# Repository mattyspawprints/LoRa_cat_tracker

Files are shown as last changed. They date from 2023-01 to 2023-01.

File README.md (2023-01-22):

# LoRa_cat_tracker :smiley_cat:
This cat tracker sends GPS coordinates using LoRa

A Raspberry Pi receives the data and sets a marker at your cat's position onto a map

There is also a portable receiver in case the Raspberry Pi doesn’t receive the data, or you have to search for your cat/collar

leaflet leaflet

©Gregor Wiebe | [Huckleberryking](https://www.huckleberryking.com/)

leaflet

[map](http://hs-augsburg.de/~lekr6621/Mattys_Website/final.html)

## Parts List
Before you buy one of the LoRa boards, check if the board has the correct frequency
- Europe EU868 MHz 
- South America AU915/AS923-1 MHz 
- North America US915 MHz 
- India IN865 MHz 
- Asia AS923 MHz

| Sender | portable receiver | receiver | other parts |
| --- |---| -----| -----|
| [1x CubeCell GPS-6502](https://www.amazon.de/Seamuing-LoRaWAN-Development-ASR6502-intelligente/dp/B08B1G5THB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,aps,110&sr=8-1-spons&sp_csd=d2lkZ2V0TmFtZT1zcF9hdGY&psc=1) | [1x Heltec WiFi LoRa 32 V2](https://www.amazon.de/Display-Entwicklungsboard-Bluetooth-868MHz-915MHz-Flash-IOT/dp/B0B6G8ZVNT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,aps,91&sr=8-7-spons&sp_csd=d2lkZ2V0TmFtZT1zcF9tdGY&th=1) | [1x Raspberry Pi 3](https://www.amazon.de/Raspberry-Pi-Model-ARM-Cortex-A53-Bluetooth/dp/B01CD5VC92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,aps,121&sr=8-2) |[2x 1k resistor](https://www.amazon.de/Widerstand-St%C3%BCck-Kohleschicht-Widerst%C3%A4nde-Resistor/dp/B00IYT9MLC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,aps,87&sr=8-8)|
| [1x Lithium Polymer Battery 3,7V 480mAh](https://www.amazon.de/EEMB-Lithium-Polymer-Ionen-Akku-wiederaufladbarer-Lithium-Ionen-Polymer-Akku-JST-Anschluss/dp/B09DPPXRFY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,7%20480mah&qid=1673031959&sprefix=lipo%203%207%20480mah,aps,85&sr=8-1-spons&sp_csd=d2lkZ2V0TmFtZT1zcF9hdGY&psc=1) | [1x Lithium Polymer Battery 3,7V 1100mAh](https://www.amazon.de/1100mAh-Schutzplatine-Isolierband-1-25-Stecker-ESP32-Entwicklungsplatine/dp/B087LTZW61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,aps,108&sr=8-6) | [1x LoRa breakout board](https://www.amazon.de/gp/product/B084NWDFH1/ref=ppx_yo_dt_b_asin_title_o01_s01?ie=UTF8&psc=1) |[1x 2k resistor](https://www.amazon.de/Widerstand-St%C3%BCck-Kohleschicht-Widerst%C3%A4nde-Resistor/dp/B00IYTI6LE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,aps,85&sr=8-6)|
| [1x active buzzer](https://www.amazon.de/QWORK-Elektronischer-Summer-Active-Kabell%C3%A4nge/dp/B09RFH1T8J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) | [(1x tactile button)](https://www.amazon.de/Youmile-100er-Pack-Miniatur-Mikro-Taster-Tastschalter-Qualit%C3%A4tsschalter-Miniature-6-x-5-mm/dp/B07Q1BXV7T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,aps,124&sr=1-1-26e67082-4f95-42ef-935f-dfc82714a173&th=1) |  |[2x slide switch](https://www.amazon.de/dp/B07VFW4SWS?psc=1&ref=ppx_yo2ov_dt_b_product_details)|
| [1x BLE hm-10 module](https://www.amazon.de/DSD-TECH-Bluetooth-iBeacon-Arduino/dp/B06WGZB2N4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,aps,94&sr=8-1-spons&sp_csd=d2lkZ2V0TmFtZT1zcF9hdGY&psc=1) | [4x Neopixels (1x strip)](https://www.amazon.de/BTF-LIGHTING-adressierbar-Vollfarbiger-wasserdichte-DIY-Projekte/dp/B088FK4SMQ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,aps,85&sr=8-15&th=1) |  |[1x ttl converter](https://www.amazon.de/dp/B089QJZ51Z?ref=ppx_yo2ov_dt_b_product_details&th=1)|
| | |  |[some jumper wires](https://www.amazon.de/AZDelivery-Jumper-Arduino-Raspberry-Breadboard/dp/B074P726ZR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)|
|  | | | [1x breadboard](https://www.amazon.de/AZDelivery-Breadboard-Steckbrett-Kontakten-Arduino/dp/B07K8PQ4B5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,aps,97&sr=8-3&th=1)|

## Case
#### 3D printed
You can print a case for the portable receiver and the sender

  
                                               
                                              ©Gregor Wiebe | [Huckleberryking](https://www.huckleberryking.com/)

  but the case for the sender is a little bit too big for a cat, in my opinion

#### alternative
If you cannot print a 3D case, you also can use heat shrink tubes for the sender and a plastic box for the receiver.
To fit everything in the tube you should use one with at least an inner diameter of 30mm.
For the receiver, you can use, for example, the box that the Heltec board came with. Make holes for the antenna, power switch, display and USB port. In this case, you can use the programable button on the board because the plastic is very thin, and you can push the button through the plastic, so choose the Portable_Receiver_onboardButton sketch and upload it to the white heltec board.

 

 

 

©Gregor Wiebe | [Huckleberryking](https://www.huckleberryking.com/)

 ##  Soldering
 
**Sender**



To make the sender thinner, you can try to remove the plastic socket
Or try to desolder the oled display

  

BLE module: solder wires to gnd and vcc (before you desolder the pin header, you have to configure your BL module, which will be explained later
Also, the red wire of the buzzer to pin 4 and the black one to gnd



Take the connector cable of the CubeCell board and connect the red wire with 
The red wire of the BLE module. Solder these cables to the middle pin of the 
Switch. Take the red battery wire and solder it to the correct pin of the switch.
Solder the three black ground wires together.

**Portable Receiver**



Take the neopixels and solder three wires to it
The data wire to pin 23 of the Heltec board
Vcc to the 3.3 pin
gnd to gnd

Use the connector cable and solder the red wire to the middle pin of the switch
And the lipo red wire to the correct pin

Do this only if you are using the printed case:
Solder a black wire to another gnd pin of the Heltec board, then solder a 1 k resistor 
to The end of the wire. Take the resistor and solder it to one pin of the tactile
Button. On the correct pin solder a wire to it, and this wire to pin 17 of the 
Board. Now solder a wire to the other pin of the pin and the 3.3V pin

Now you can put everything in the receiver case

**Raspberry Pi Receiver**



Solder 11 wires to the LoRa breakout board 
And the antenna to the antenna pin
|Raspberry Pi  | Lora – SX1276 Module |
|--|--|
| 3.3V | 3.3V |
| gnd | gnd |
| GPIO 10 | MOSI |
| GPIO 9 | MISO |
| GPIO 11 | SCK |
| GPIO 8 | Nss / Enable |
| GPIO 4 | DIO 0 |
| GPIO 17 | DIO 1 |
| GPIO 18 | DIO 2 |
| GPIO 27 | DIO 3 |
| GPIO 22 | RST |

 ##  Software
 
### Arduino IDE

Go to https://www.arduino.cc/en/software and download the Arduino IDE

Next, we have to include the libraries for the Heltec boards. 
Open the Arduino IDE and go to file -> preferences
Click on the two squares and paste the three links into it

https://dl.espressif.com/dl/package_esp32_index.json                                                                                  
https://github.com/HelTecAutomation/CubeCell-Arduino/releases/download/V1.5.0/package_CubeCell_index.json                                                    
https://github.com/Heltec-Aaron-Lee/WiFi_Kit_series/releases/download/0.0.6/package_heltec_esp32_index.json

  

### **Sender**

Connect the CubeCell board to your computer and choose the port and the correct board from the manager.

choosing board github ports
  
To test the CubeCell board upload the oledDisplayGPSInfo.ino file
file->examples->OnBoardGPS ->  oledDisplayGPSInfo -> ctrl + u.
If there’s an compile error try to replace line 8 with this 

`SSD1306Wire  display(0x3c, 500000, SDA, SCL ,GEOMETRY_128_64,GPIO10); // addr, freq, sda, scl,resolution, rst`

Put the board outside and wait until the board gets a GPS fix
First time using it could take some time until it gets a fix
Next time it is much faster

If everything is working open the sender sketch which is in the github folder you’ve downloaded

 

 **GPS settings**
 
The default GPS settings are GPS_INIT_TIMEOUT 5 Minutes, 
GPS_SLEEPTIME also 5 Minutes, GPS_UPDATE_TIMEOUT 30 seconds.
If you want that your tracker sleeps longer you can change the sleeptime.
The numbers are in milliseconds. (1 sec = 1000ms)

**LoRa settings**

choose your frequency : 
- Europe EU868 MHz
- South America  AU915/AS923-1 MHz
- North America US915 MHz
- India  IN865 MHz
- Asia AS923 MHz

You also can change the bandwidth, codingrate and spreading factor. Keep in mind if you change these settings you have to change them 
in the code for the receivers too.
Upload the code (ctrl + u)

### **Portable Receiver**

 Now connect the Heltec WiFi board to your computer. Open the portable receiver sketch (downloaded github folder) and choose the Heltec Wifi LoRa V2 and the port.
 
portable receiver frequency

In line 284 change the LoRa frequency. This time it’s called band.



Here you can change the bandwidth, codingrate and sprading factor.
But it has to be the same settings like in the sender sketch.

 

On the left side click on the library manager and search for adafruit neopixel. Install the Adafruit NeoPixel by Adafruit.

Upload the code



BT -> bluetooth connection with senders ble module, the number is the signalstrength

V -> it receives the senderes battery capacity in millivolts

LoRa: 
- zone -> you can set a zone to now wheres your pet at instead of only coordinates
- numbers -> senders coordinates
- RSSI -> LoRa signalstrength
    
### **Raspberry Pi Receiver**

For this receiver I’m using this repository: https://github.com/rpsreal/pySX127x

Download the Raspberry Pi Imager from here: https://www.raspberrypi.com/software/
and Visual Studio Code https://code.visualstudio.com/
Open the imager and insert a micro sd cart into your computer.

rp-imager

Choose the Raspberry Pi Os (32-Bit) operating system and your sd card.
Click on the gear and configurate following settings.

rp-imager settings

- enable Hostname: raspberrypi
- enable ssh
- enter pi as username and choose a password
- set your Wifi SSID and password
- set your country

Save everything and click on the write button
After the os is written to your sd card you can remove it and insert it into your Raspberry Pi. Plug the power cable into your Pi.
Open Visual Studio Code and click on the left side on the extensions icon. Search for remote ssh and install it.





Wait couple minutes to let your Pi boot up.
Click on the green icon in the bottom left corner and choose connect current window to host -> add new ssh host -> write ssh pi@raspberrypi and press enter -> C:\user\.ssh\config -> click again on the green icon in the bottom left corner and choose connect current window to host -> Linux -> raspberrypi -> continue -> enter your password 
Now you are connected to your Pi. Click on file -> open folder -> \home\pi
Terminal -> new terminal
enter every line and press enter if it ask to continue enter y

    sudo apt-get update
    sudo apt-get upgrade
    sudo apt-get install apache2
    sudo mkdir /var/www/html/tracker
  
    sudo raspi-config nonint do_spi 0
    sudo apt-get install python-dev python3-dev
    sudo apt-get install python-pip python3-pip
    
    pip install RPi.GPIO
    pip install spidev
    pip install pyLoRa

    sudo apt-get install git
    git clone https://github.com/rpsreal/pySX127x

After everything is installed enter sudo reboot. Wait a minute and connect with your pi again (green icon in the buttom left corner).

Drag the website.py file from the downloaded github folder and drop it into the pi folder in visual studio code.



Now right click under the website file -> new file -> array.txt
Go to the terminal again. To run the code enter `python3 website.py`

To stop the code press ctrl + c.



To change the LoRa settings click on the website.py file.
Remember to change your frequency and set the same bandwidth and spreading factor like the sender.

### **Map**

for the map I'm using Leaflet. You can change the pictures and the offset of the paw prints


IF you changed the code press ctrl + s and run the code. 

After your Raspberry Pi received some coordinates you can check them out here: http://raspberrypi/tracker/index.html

### **DSD TECH Bluetooth Tools**

Because i use a module from DSD TECH i configurated my module with their software 
http://www.dsdtech-global.com/2017/11/dsd-tech-bluetooth-config-tool.html
Use a ttl converter and connect 
|TTL converter| BLE module |
|--|--|
| 5V | vcc |
| gnd | gnd |
| RX | TX |
| TX | RX |

 



In the software choose your com port, click on open and go to the hm-10 tab
Click on ‘test’ to check if there is a connection

If in the consol comes a ok back everything is good

First change the modules name (e.g. your cats name) -> set

Auth Mode: Auth not need PIN -> set

PIN: choose a pin  -> set




Go to the AT Comand tab

ASCII: 

AT+PWRM0 -> send		(auto sleep)

AT+MODE2 -> send		(Remote Control Mode + Transmission Mode)

AT+BEFC000 -> send		(Set Module pin output state, After power supplied)

AT+AFTC000 -> send		(Set Module pin output state, After connection is established) 
In my case i wasn’t able to change the service and characteristics uuid with ascii (AT+UUID0xFFE4 | AT+CHAR0xFFE5) so i converted these two camands in hexadecimal

HEX:

41 54 2B 55 55 49 44 30 78 46 46 45 34    ->    send	(Service uuid)

41 54 2B 43 48 41 52 30 78 46 46 45 35    ->    send	(characteristics uuid)

Now your module is configurated. Click on close icon and unplug the ttl converter. Plug it again into your computer and search with your smartphone for bluetooth devices. If you are able to find your module with the name you set everything is fine.
If you have an iPhone it coul be possible that you are unable to see the module in your bluetooth devices.
Take the portable receiver and press the button now it will search for the ble module. When they are connected the neopixels begin to glow and show the distance between these two devices.

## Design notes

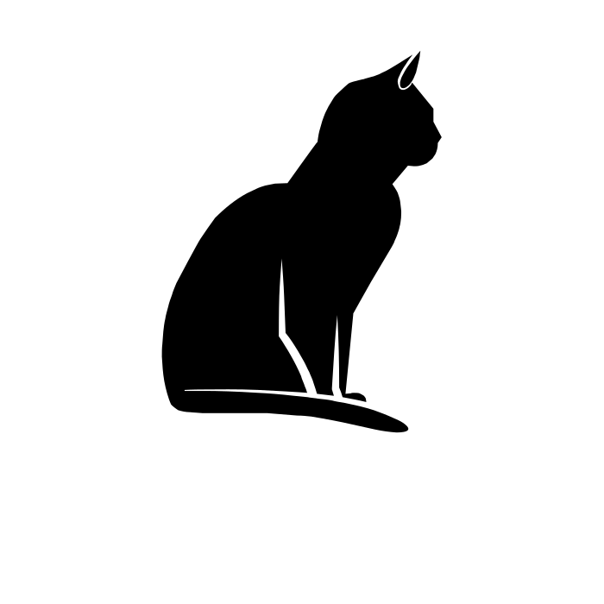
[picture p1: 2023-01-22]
Leaflet/images/noun-black-cat.png

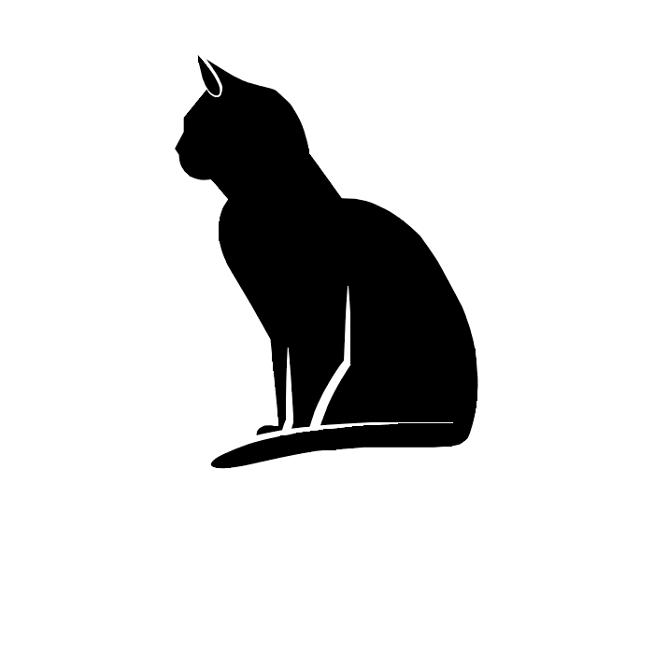
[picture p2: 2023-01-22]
Leaflet/images/black_cat_left.png

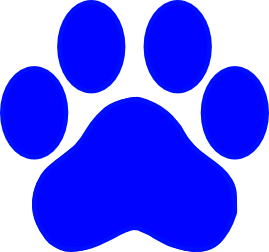
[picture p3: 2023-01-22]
Leaflet/images/pawBlue.png

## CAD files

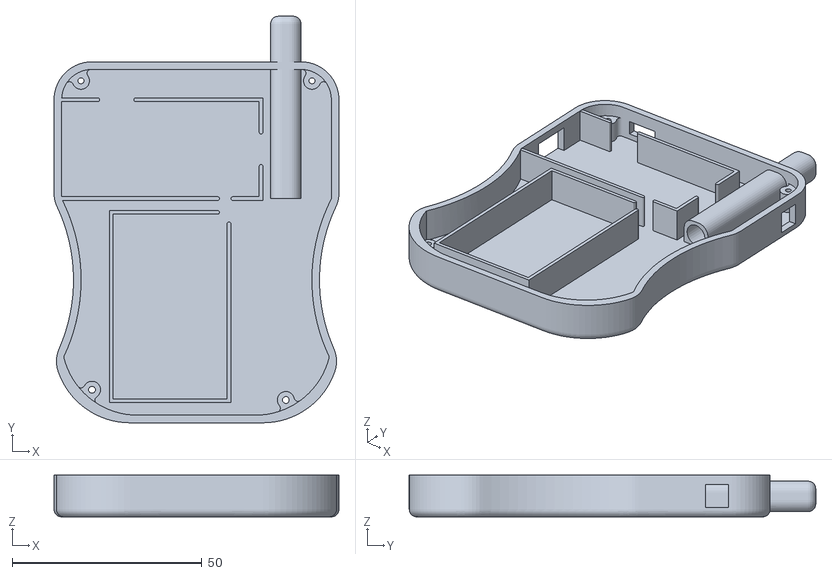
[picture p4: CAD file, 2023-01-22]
3D Cases/Portable_Receiver/Portable_Receiver_bottom.stl
75.0 x 107.0 x 11.0

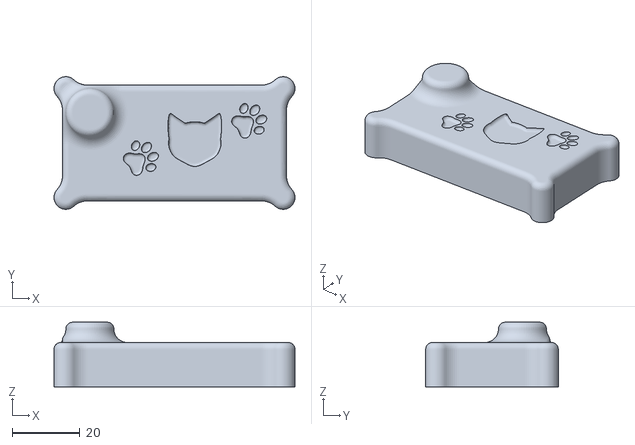
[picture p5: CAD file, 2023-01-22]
3D Cases/Sender/Sender_top.stl
71.2 x 39.2 x 19.1

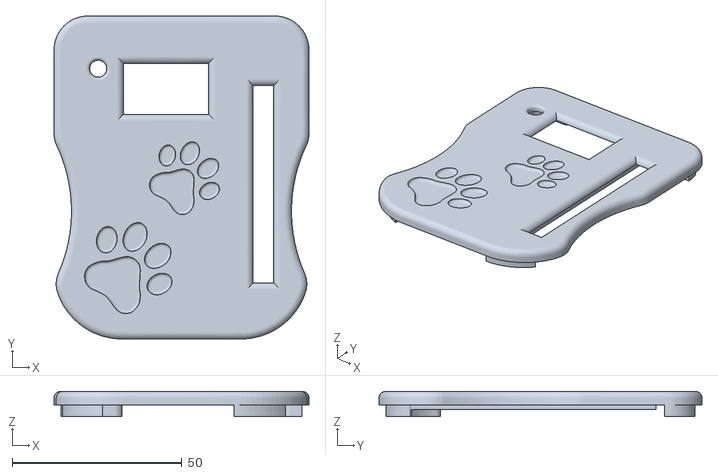
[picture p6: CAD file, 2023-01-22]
3D Cases/Portable_Receiver/Portable_Receiver_top.stl
75.0 x 95.0 x 7.50

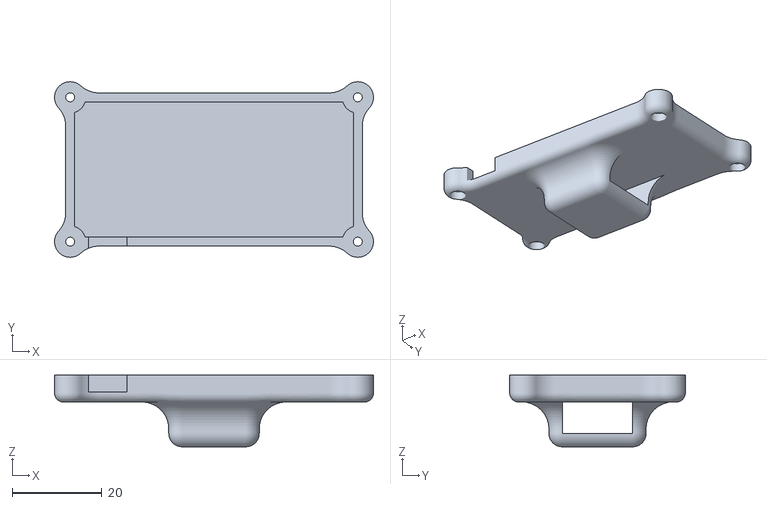
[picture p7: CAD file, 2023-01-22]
3D Cases/Sender/Sender_bottom.stl
71.2 x 39.2 x 16.0

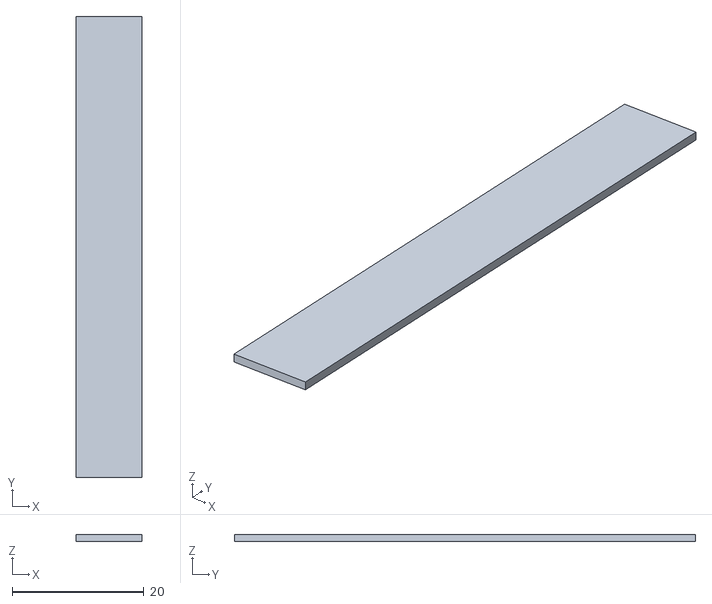
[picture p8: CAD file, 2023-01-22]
3D Cases/Portable_Receiver/Portable_Receiver_transperent.stl
10.0 x 70.0 x 1.00

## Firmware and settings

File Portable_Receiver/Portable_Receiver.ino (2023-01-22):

#include <Adafruit_NeoPixel.h>
#ifdef __AVR__
 #include <avr/power.h> // Required for 16 MHz Adafruit Trinket
#endif

// Which pin on the Arduino is connected to the NeoPixels?
#define PIN        23 // On Trinket or Gemma, suggest changing this to 1

// How many NeoPixels are attached to the Arduino?
#define NUMPIXELS 4 // Popular NeoPixel ring size

#define buttonPin 17

int buttonValue = 0;

int bright;

Adafruit_NeoPixel pixels(NUMPIXELS, PIN, NEO_GRB + NEO_KHZ800);

#define DELAYVAL 500 // Time (in milliseconds) to pause between pixels



#include "heltec.h"


#include "BLEDevice.h"

//BLE

/* Specify the Service UUID of Server */
static BLEUUID serviceUUID("0000ffe4-0000-1000-8000-00805f9b34fb");
/* Specify the Characteristic UUID of Server */
static BLEUUID    charUUID("0000ffe5-0000-1000-8000-00805f9b34fb");

static boolean doConnect = false;
static boolean connected = false;
static boolean doScan = false;
static BLERemoteCharacteristic* pRemoteCharacteristic;
static BLEAdvertisedDevice* myDevice;

bool deviceConnected = false;
bool oldDeviceConnected = false;

BLEClient*  pClient  = BLEDevice::createClient();

String rssiBLE = "";
int rssiLED;
String bluet = "N/A";

static void notifyCallback(BLERemoteCharacteristic* pBLERemoteCharacteristic,
                            uint8_t* pData, size_t length, bool isNotify)
{
  Serial.print("Notify callback for characteristic ");
  Serial.print(pBLERemoteCharacteristic->getUUID().toString().c_str());
  Serial.print(" of data length ");
  Serial.println(length);
  Serial.print("data: ");
  Serial.println((char*)pData);
}

class MyClientCallback : public BLEClientCallbacks
{
  void onConnect(BLEClient* pclient)
  {
    deviceConnected = true;
  }

  void onDisconnect(BLEClient* pclient)
  {
    deviceConnected = false;
    connected = false;
  }
};

/* Start connection to the BLE Server */
bool connectToServer()
{
 
  pClient->setClientCallbacks(new MyClientCallback());

    /* Connect to the remote BLE Server */
  pClient->connect(myDevice);  // if you pass BLEAdvertisedDevice instead of address, it will be recognized type of peer device address (public or private)
  Heltec.display->drawString(45, 0, "bonding");
     Heltec.display->display();


    /* Obtain a reference to the service we are after in the remote BLE server */
  BLERemoteService* pRemoteService = pClient->getService(serviceUUID);
  if (pRemoteService == nullptr)
  {
    pClient->disconnect();
    return false;
  }



  /* Obtain a reference to the characteristic in the service of the remote BLE server */
  pRemoteCharacteristic = pRemoteService->getCharacteristic(charUUID);
  if (pRemoteCharacteristic == nullptr)
  {
    pClient->disconnect();
    return false;
  }
  Serial.println(" - Found our characteristic");

  /* Read the value of the characteristic */
  /* Initial value is 'Hello, World!' */
  if(pRemoteCharacteristic->canRead())
  {
    std::string value = pRemoteCharacteristic->readValue();
  }

  if(pRemoteCharacteristic->canNotify())
  {
    pRemoteCharacteristic->registerForNotify(notifyCallback);

  }

    connected = true;
    return true;
}
/* Scan for BLE servers and find the first one that advertises the service we are looking for. */
class MyAdvertisedDeviceCallbacks: public BLEAdvertisedDeviceCallbacks
{
 /* Called for each advertising BLE server. */
  void onResult(BLEAdvertisedDevice advertisedDevice)
  {

    /* We have found a device, let us now see if it contains the service we are looking for. */
    if (advertisedDevice.haveServiceUUID() && advertisedDevice.isAdvertisingService(serviceUUID))
    {
      BLEDevice::getScan()->stop();
      myDevice = new BLEAdvertisedDevice(advertisedDevice);
      doConnect = true;
      doScan = true;

    }
  }
};


void onButton(){
  Serial.println("button pressed");
  if(connected){
    // String newValue = "beep"; //String für Buzzer am CubeCell Board
    String newValue = "AT+PIO41"; //String für Buzzer direkt am BLE Modul
    Serial.println(newValue);

    
    /* Set the characteristic's value to be the array of bytes that is actually a string */
    pRemoteCharacteristic->writeValue(newValue.c_str(), newValue.length());
    /* You can see this value updated in the Server's Characteristic */
        delay(500); // bluetooth stack will go into congestion, if too many packets are sent, in 6 hours test i was able to go as low as 3ms
        newValue = "AT+PIO40";
        pRemoteCharacteristic->writeValue(newValue.c_str(), newValue.length());    
  }else {
          Heltec.display->drawString(45, 0, "search");
          Heltec.display->display();
          BLEDevice::init("ESP32-BLE-Client");

          esp_ble_tx_power_set(ESP_BLE_PWR_TYPE_DEFAULT, ESP_PWR_LVL_P9); 
          esp_ble_tx_power_set(ESP_BLE_PWR_TYPE_ADV, ESP_PWR_LVL_P9);
          esp_ble_tx_power_set(ESP_BLE_PWR_TYPE_SCAN ,ESP_PWR_LVL_P9);  



            /* Retrieve a Scanner and set the callback we want to use to be informed when we
              have detected a new device.  Specify that we want active scanning and start the
              scan to run for 5 seconds. */
            BLEScan* pBLEScan = BLEDevice::getScan();
            pBLEScan->setAdvertisedDeviceCallbacks(new MyAdvertisedDeviceCallbacks());
            pBLEScan->setInterval(1349);
            pBLEScan->setWindow(449);
            pBLEScan->setActiveScan(true);
            pBLEScan->start(10, false);
            }
   

}

//battery
#include <Arduino.h>
#include <esp_adc_cal.h>
#include <driver/adc.h>
#define MAXBATT                 4200    // The default Lipo is 4200mv when the battery is fully charged.
#define LIGHT_SLEEP_VOLTAGE     3750    // Point where start light sleep
#define MINBATT                 3200    // The default Lipo is 3200mv when the battery is empty...this WILL be low on the 3.3v rail specs!!!

#define VOLTAGE_DIVIDER         3.20    // Lora has 220k/100k voltage divider so need to reverse that reduction via (220k+100k)/100k on vbat GPIO37 or ADC1_1 (early revs were GPIO13 or ADC2_4 but do NOT use with WiFi.begin())
#define DEFAULT_VREF            1100    // Default VREF use if no e-fuse calibration
#define VBATT_SAMPLE            500     // Battery sample rate in ms
#define VBATT_SMOOTH            50      // Number of averages in sample
#define ADC_READ_STABILIZE      5       // in ms (delay from GPIO control and ADC connections times)
#define LO_BATT_SLEEP_TIME      10*60*1000*1000     // How long when low batt to stay in sleep (us)
#define HELTEC_V2_1             1       // Set this to switch between GPIO13(V2.0) and GPIO37(V2.1) for VBatt ADC.
#define VBATT_GPIO              21      // Heltec GPIO to toggle VBatt read connection ... WARNING!!! This also connects VEXT to VCC=3.3v so be careful what is on header.  Also, take care NOT to have ADC read connection in OPEN DRAIN when GPIO goes HIGH
#define __DEBUG                 0       // DEBUG Serial output

uint16_t Sample();
void drawBattery(uint16_t, bool = false);

esp_adc_cal_characteristics_t *adc_chars;

// Poll the proper ADC for VBatt on Heltec Lora 32 with GPIO21 toggled
uint16_t ReadVBatt() {
  uint16_t reading = 666;

  digitalWrite(VBATT_GPIO, LOW);              // ESP32 Lora v2.1 reads on GPIO37 when GPIO21 is low
  delay(ADC_READ_STABILIZE);                  // let GPIO stabilize
  #if (defined(HELTEC_V2_1))
  pinMode(ADC1_CHANNEL_1, OPEN_DRAIN);        // ADC GPIO37
  reading = adc1_get_raw(ADC1_CHANNEL_1);
  pinMode(ADC1_CHANNEL_1, INPUT);             // Disconnect ADC before GPIO goes back high so we protect ADC from direct connect to VBATT (i.e. no divider)
  #else
  pinMode(ADC2_CHANNEL_4, OPEN_DRAIN);        // ADC GPIO13
  adc2_get_raw(ADC2_CHANNEL_4,ADC_WIDTH_BIT_12,&reading);
  pinMode(ADC2_CHANNEL_4, INPUT);             // Disconnect ADC before GPIO goes back high so we protect ADC from direct connect to VBATT (i.e. no divider
  #endif

  uint16_t voltage = esp_adc_cal_raw_to_voltage(reading, adc_chars);  
  voltage*=VOLTAGE_DIVIDER;

  return voltage;
}

//  Use a buffer to average/sample ADC
uint16_t Sample() {
  static uint8_t i = 0;
  static uint16_t samp[VBATT_SMOOTH];
  static int32_t t = 0;
  static bool f = true;
  if(f){ for(uint8_t c=0;c<VBATT_SMOOTH;c++){ samp[c]=0; } f=false; }   // Initialize the sample array first time
  t -= samp[i];   // doing a rolling recording, so remove the old rolled around value out of total and get ready to put new one in.
  if (t<0) {t = 0;}

  // ADC read
  uint16_t voltage = ReadVBatt();

  samp[i]=voltage;
  #if defined(__DEBUG) && __DEBUG > 0

  #endif
  t += samp[i];

  if(++i >= VBATT_SMOOTH) {i=0;}
  uint16_t s = round(((float)t / (float)VBATT_SMOOTH));
  #if defined(__DEBUG) && __DEBUG > 0

  #endif

  return s;
}


void drawBattery(uint16_t voltage, bool sleep) {

  uint16_t v = voltage;
  if (v < MINBATT) {v = MINBATT;}
  if (v > MAXBATT) {v = MAXBATT;}
  double pct = map(v,MINBATT,MAXBATT,0,100);
  uint8_t bars = round(pct / 10.0);

  uint16_t rnd = round(voltage/10.0);
  Serial.println(rnd);

  if (rnd > 413 || rnd < 380){
    Heltec.display->drawString(1,14,String(round(voltage/10.0)/100.0)+"V");

  }

  #if defined(__DEBUG) && __DEBUG > 0
  static uint8_t c = 0;
  if ((c++ % 10) == 0) {
    c = 1;
 
  }
  #endif
}



//LoRa
#define BAND    868E6  //you can set band here directly,e.g. 868E6,915E6
String rssiLoRa = " ";
String snr = " ";
String packSize = "--";
String packet ;
String str ;
String sublat ;
// int sublatsplit ;
String sublon ;
// int sublonsplit ;
String position;
String battery;

String fence;
int indexLON ;
int indexV ;


void DisplayData(){
  Heltec.display->clear();

  //battery
  uint16_t voltage = Sample();
  drawBattery(voltage, voltage < LIGHT_SLEEP_VOLTAGE);

  //BLE
  Heltec.display->drawString(0, 0, bluet);  
  Heltec.display->drawString(25, 0, rssiBLE); 

  //LoRa
  Heltec.display->drawString(0, 30, "LoRa:");
  Heltec.display->drawString(10, 45, position); 
  Heltec.display->drawStringMaxWidth(35 , 30 , 128, fence);
 
  Heltec.display->drawStringMaxWidth(85 , 0 , 128, battery);   
  Heltec.display->drawString(100, 20, snr); 
  Heltec.display->drawString(100, 30, rssiLoRa);  
  Heltec.display->display();
}

void cbk(int packetSize) {
  packet ="";

  packSize = String(packetSize,DEC);
  for (int i = 0; i < packetSize; i++) { packet += (char) LoRa.read();  }
  rssiLoRa = String(LoRa.packetRssi(), DEC) ;
  snr = (LoRa.packetSnr(), DEC) ;
  

  
  str = packet;
  indexLON = str.indexOf(' ');
  indexV = str.indexOf('V');
  sublat = str.substring(0, indexLON);
  sublon = str.substring(indexLON + 1, indexV - 5);
  battery = str.substring(indexV - 4, indexV + 1);
  position = sublat + " " + sublon;
  
  //setting zones
  if (sublat.toFloat() > 48.741537 && sublat.toFloat() < 48.741653 && sublon.toFloat() > 10.788777 && sublon.toFloat() < 10.789115) {
    fence = "at home";
  }else if(sublat.toFloat() > 48.739608 && sublat.toFloat() < 48.740880 && sublon.toFloat() > 10.790100 && sublon.toFloat() < 10.790737){
    fence = "forest";
  }else {
    fence = "unknown";
  }
  
}


void setup()
{
  Heltec.begin(true /*DisplayEnable Enable*/, true /*Heltec.Heltec.Heltec.LoRa Disable*/, true /*Serial Enable*/, true /*PABOOST Enable*/, BAND /*long BAND*/);
  
  //battery
  // Characterize ADC at particular atten
  #if (defined(HELTEC_V2_1))
  adc_chars = (esp_adc_cal_characteristics_t*)calloc(1, sizeof(esp_adc_cal_characteristics_t));
  esp_adc_cal_value_t val_type = esp_adc_cal_characterize(ADC_UNIT_1, ADC_ATTEN_DB_6, ADC_WIDTH_BIT_12, DEFAULT_VREF, adc_chars);
  adc1_config_width(ADC_WIDTH_BIT_12);
  adc1_config_channel_atten(ADC1_CHANNEL_1,ADC_ATTEN_DB_6);
  #else
  // Use this for older V2.0 with VBatt reading wired to GPIO13
  adc_chars = (esp_adc_cal_characteristics_t*)calloc(1, sizeof(esp_adc_cal_characteristics_t));
  esp_adc_cal_value_t val_type = esp_adc_cal_characterize(ADC_UNIT_2, ADC_ATTEN_DB_6, ADC_WIDTH_BIT_12, DEFAULT_VREF, adc_chars);
  adc2_config_channel_atten(ADC2_CHANNEL_4,ADC_ATTEN_DB_6);
  #endif

  #if defined(__DEBUG) && __DEBUG > 0
  Serial.printf("ADC Calibration: ");
  if (val_type == ESP_ADC_CAL_VAL_EFUSE_VREF) {
      Serial.printf("eFuse Vref\n");
  } else if (val_type == ESP_ADC_CAL_VAL_EFUSE_TP) {
      Serial.printf("Two Point\n");
  } else {
      Serial.printf("Default[%dmV]\n",DEFAULT_VREF);
  }
  #else
  if (val_type);    // Suppress warning
  #endif

 #if defined(__DEBUG) && __DEBUG >= 1
 
  #else
  if (val_type);    // Suppress warning
  #endif

  // Prime the Sample register
  for (uint8_t i = 0;i < VBATT_SMOOTH;i++) {
    Sample();
  }

  pinMode(VBATT_GPIO,OUTPUT);
  digitalWrite(VBATT_GPIO, LOW);              // ESP32 Lora v2.1 reads on GPIO37 when GPIO21 is low
  delay(ADC_READ_STABILIZE);                  // let GPIO stabilize




  //LoRa

  //LoRa.setSpreadingFactor(7);
  LoRa.setSpreadingFactor(9);
  // LoRa.setSignalBandwidth(250E3);
  LoRa.setSignalBandwidth(125E3);
  // LoRa.setSignalBandwidth(41.7E3);
  LoRa.setCodingRate4(1);
  LoRa.setSyncWord(0x12);   //0x34
  LoRa.setPreambleLength(8);
  
  //display
  
  Heltec.display->init(); 
  Heltec.display->setFont(ArialMT_Plain_10);
  Heltec.display->drawString(0, 0, "Empfänger");
  Heltec.display->display();
  delay(500);
  Heltec.display->clear();
  Heltec.display->display();

  #if defined(__AVR_ATtiny85__) && (F_CPU == 16000000)
  clock_prescale_set(clock_div_1);
  #endif
  // END of Trinket-specific code.

  pixels.begin(); // INITIALIZE NeoPixel strip object (REQUIRED)
  pixels.setBrightness(50);
  pixels.clear();
  pixels.show();
  Serial.println("Starting Arduino BLE Client application...");
  pinMode(buttonPin, INPUT);
}


void loop()
{

int packetSize = LoRa.parsePacket();
  if (packetSize) { cbk(packetSize);  }
  delay(10);   

  DisplayData();
 rssiBLE = pClient->getRssi();
 rssiLED = pClient->getRssi();
  buttonValue =  digitalRead(buttonPin);
Serial.println(buttonValue);

   if (!deviceConnected) {
    bluet = "N/A";

    pixels.clear();
      pixels.setPixelColor(0, pixels.Color(0, 0, 0));
      pixels.setPixelColor(1, pixels.Color(0, 0, 0));
      pixels.setPixelColor(2, pixels.Color(0, 0, 0));
      pixels.setPixelColor(3, pixels.Color(125, 0, 255));
      
      pixels.show();
   }else{
    bluet = "BT";

    if (rssiLED < -140){
      pixels.clear();
      pixels.setPixelColor(0, pixels.Color(255, 0, 0));
      pixels.setPixelColor(1, pixels.Color(0, 0, 0));
      pixels.setPixelColor(2, pixels.Color(0, 0, 0));
      pixels.setPixelColor(3, pixels.Color(0, 0, 0));
      
      pixels.show();
    }else if (rssiLED < -110){
      pixels.clear();
      pixels.setPixelColor(0, pixels.Color(255, 0, 0));
      pixels.setPixelColor(1, pixels.Color(255, 0, 0));
      pixels.setPixelColor(2, pixels.Color(0, 0, 0));
      pixels.setPixelColor(3, pixels.Color(0, 0, 0));
     
      pixels.show();
    }else if (rssiLED < -105){
      pixels.clear();
      pixels.setPixelColor(0, pixels.Color(255, 0, 0));
      pixels.setPixelColor(1, pixels.Color(255, 0, 0));
      pixels.setPixelColor(2, pixels.Color(255, 0, 0));
      pixels.setPixelColor(3, pixels.Color(0, 0, 0));
      
      pixels.show();
    }else if (rssiLED < -100){
      pixels.clear();
      pixels.setPixelColor(0, pixels.Color(255, 0, 0));
      pixels.setPixelColor(1, pixels.Color(255, 0, 0));
      pixels.setPixelColor(2, pixels.Color(255, 0, 0));
      pixels.setPixelColor(3, pixels.Color(255, 0, 0));
 
      pixels.show();
    }else if (rssiLED < -90){
      pixels.clear();
      pixels.setPixelColor(0, pixels.Color(0, 255, 0));
      pixels.setPixelColor(1, pixels.Color(255, 0, 0));
      pixels.setPixelColor(2, pixels.Color(255, 0, 0));
      pixels.setPixelColor(3, pixels.Color(255, 0, 0));
      
      pixels.show();
    }else if (rssiLED < -70){
      pixels.clear();
      pixels.setPixelColor(0, pixels.Color(0, 255, 0));
      pixels.setPixelColor(1, pixels.Color(0, 255, 0));
      pixels.setPixelColor(2, pixels.Color(255, 0, 0));
      pixels.setPixelColor(3, pixels.Color(255, 0, 0));
      
      pixels.show();
    }else if (rssiLED < -60){
      pixels.clear();
      pixels.setPixelColor(0, pixels.Color(0, 255, 0));
      pixels.setPixelColor(1, pixels.Color(0, 255, 0));
      pixels.setPixelColor(2, pixels.Color(0, 255, 0));
      pixels.setPixelColor(3, pixels.Color(255, 0, 0));
      
      pixels.show();   
    }else if (rssiLED < -50){
      pixels.clear();
      pixels.setPixelColor(0, pixels.Color(0, 255, 0));
      pixels.setPixelColor(1, pixels.Color(0, 255, 0));
      pixels.setPixelColor(2, pixels.Color(0, 255, 0));
      pixels.setPixelColor(3, pixels.Color(0, 255, 0));
      
      pixels.show();
    }else {
      pixels.clear();
      pixels.setPixelColor(0, pixels.Color(0, 0, 0));
      pixels.setPixelColor(1, pixels.Color(0, 0, 0));
      pixels.setPixelColor(2, pixels.Color(0, 255, 180));
      pixels.setPixelColor(3, pixels.Color(0, 255, 180));
      
      pixels.show();
    }
   }
  
  if (buttonValue == 1){
    onButton();    
  }

  /* If the flag "doConnect" is true, then we have scanned for and found the desired
     BLE Server with which we wish to connect.  Now we connect to it.  Once we are 
     connected we set the connected flag to be true. */
  if (doConnect == true)
  {
    if (connectToServer())
    {
      Serial.println("We are now connected to the BLE Server.");
    } 
    else
    {
      Serial.println("We have failed to connect to the server; there is nothin more we will do.");
    }
    doConnect = false;
  }

if (!deviceConnected && oldDeviceConnected) { 
        oldDeviceConnected = deviceConnected;

    }
    // connecting
    if (deviceConnected && !oldDeviceConnected) {
        // do stuff here on connecting
        oldDeviceConnected = deviceConnected;
    }  


  /* If we are connected to a peer BLE Server, update the characteristic each time we are reached
     with the current time since boot */
  
  
  
  delay(500); /* Delay a second between loops */
}

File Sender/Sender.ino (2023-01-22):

#include <Arduino.h>
#include "GPS_Air530Z.h"
#include "LoRaWan_APP.h"



//if GPS module is Air530Z, use this
Air530ZClass GPS;

typedef enum {
  STATUS_LPM = 0,
  STATUS_UPDATE_GPS
} dev_status;

int indexnew;
char str_latitude[27];
char str_longitude[27];
int counter = 0;

//fisrt fix timeout
#define GPS_INIT_TIMEOUT 300000  // 300sec/5min

//sleep time until next GPS update
#define GPS_SLEEPTIME 300000  // 300sec/5min


//when gps waked, if in GPS_UPDATE_TIMEOUT, gps not fixed then into low power mode
#define GPS_UPDATE_TIMEOUT 30000  // 30sec/0,5min

//once fixed, GPS_CONTINUE_TIME later into low power mode
#define GPS_CONTINUE_TIME 5000  // 5sec/

static TimerEvent_t autoGPS;
dev_status mcu_status;
uint32_t starttime;

int32_t fracPart(double val, int n) {
  return (int32_t)((val - (int32_t)(val)) * pow(10, n));
}


/*
 * set LoraWan_RGB to 1,the RGB active in loraWan
 * RGB red means sending;
 * RGB green means received done;
 */
#ifndef LoraWan_RGB
#define LoraWan_RGB 0
#endif

#define RF_FREQUENCY 868000000  // Hz

#define TX_OUTPUT_POWER 14  // dBm

#define LORA_BANDWIDTH 0         // [0: 125 kHz, \
                                 //  1: 250 kHz, \
                                 //  2: 500 kHz, \
                                 //  3: Reserved \
                                 
#define LORA_SPREADING_FACTOR 7  // [SF7..SF12]
#define LORA_CODINGRATE 1        // [1: 4/5, \
                                 //  2: 4/6, \
                                 //  3: 4/7, \
                                 //  4: 4/8]
#define LORA_PREAMBLE_LENGTH 8   // Same for Tx and Rx
#define LORA_SYMBOL_TIMEOUT 0    // Symbols
#define LORA_FIX_LENGTH_PAYLOAD_ON false
#define LORA_IQ_INVERSION_ON false


#define RX_TIMEOUT_VALUE 1000
#define BUFFER_SIZE 40  // Define the payload size here

char txpacket[BUFFER_SIZE];
char rxpacket[BUFFER_SIZE];

static RadioEvents_t RadioEvents;

double txNumber;

int16_t rssi, rxSize;
unsigned long lastMillis;

uint16_t voltage;


void onAutoGPS() {
  TimerStop(&autoGPS);
  mcu_status = STATUS_UPDATE_GPS;
}

void gpsUpdate(uint32_t timeout, uint32_t continuetime) {
  //VextOFF();// oled power on;
  delay(10);

  GPS.begin();
  starttime = millis();
  while ((millis() - starttime) < timeout) {
    while (GPS.available() > 0) {
      GPS.encode(GPS.read());
    }

    // gps fixed in a second
    if (GPS.location.age() < 1000) {
      break;
    }
  }

  //if gps fixed update gps and print gps info every 1 second
  if (GPS.location.age() < 1000) {
    starttime = millis();
    uint32_t printinfo = 0;
    while ((millis() - starttime) < continuetime) {
      while (GPS.available() > 0) {
        GPS.encode(GPS.read());
      }

      if ((millis() - starttime) > printinfo) {
        printinfo += 1000;
        int index;
        char str_la[27];
        index = sprintf(str_la, "%d.%d", (int)GPS.location.lat(), fracPart(GPS.location.lat(), 6));
        str_la[index] = 0;
    

        char str_lo[27];
        index = sprintf(str_lo, "%d.%d", (int)GPS.location.lng(), fracPart(GPS.location.lng(), 6));
        str_lo[index] = 0;


        char* cmp_la = strstr(str_la, str_latitude); 
        char* cmp_lo = strstr(str_lo, str_longitude); 

        if(cmp_la && cmp_lo){
          counter ++;

          if (counter >= 6) {          
            sprintf(txpacket + strlen(txpacket), " %s", "R");  //add to the end of package  
            Radio.Send((uint8_t *)txpacket, strlen(txpacket));  //send the package out   
            delay (500);
            CySoftwareReset();   
          }    
        }



        sprintf(txpacket, "%s %s", str_la, str_lo);  //start a package
      }
    }
  } else  //if gps no fixed waited for 2s in to lowpowermode
  {
    
    int index;
    char str_la[27];
    index = sprintf(str_la, "%d.%d", (int)GPS.location.lat(), fracPart(GPS.location.lat(), 6));
    str_la[index] = 0;

    char str_lo[27];
    index = sprintf(str_lo, "%d.%d", (int)GPS.location.lng(), fracPart(GPS.location.lng(), 6));
    str_lo[index] = 0;

    char* cmp_la = strstr(str_la, str_latitude);      
    char* cmp_lo = strstr(str_lo, str_longitude); 

     if(cmp_la && cmp_lo){       
      voltage = getBatteryVoltage();
      sprintf(txpacket + strlen(txpacket), " %d%s", voltage, "V N");  //add to the end of package  
          Radio.Send((uint8_t *)txpacket, strlen(txpacket));  //send the package out 
          delay(5000);
          CySoftwareReset();  
     }



    sprintf(txpacket, "%s %s", str_la, str_lo);  //start a package


    delay(2000);
  }

  
    indexnew = sprintf(str_latitude, "%d.%d", (int)GPS.location.lat(), fracPart(GPS.location.lat(), 6));
    str_latitude[indexnew] = 0;
    


  GPS.end();
  voltage = getBatteryVoltage();

  sprintf(txpacket + strlen(txpacket), " %d%s", voltage, "V");  //add to the end of package

  Radio.Send((uint8_t *)txpacket, strlen(txpacket));  //send the package out
  delay(1000);
  Radio.Sleep();

  delay(2000);

  TimerSetValue(&autoGPS, GPS_SLEEPTIME);
  TimerStart(&autoGPS);
}




void setup() {


  txNumber = 0;
  rssi = 0;

  Radio.Init(&RadioEvents);
  Radio.SetChannel(RF_FREQUENCY);
  Radio.SetTxConfig(MODEM_LORA, TX_OUTPUT_POWER, 0, LORA_BANDWIDTH,
                    LORA_SPREADING_FACTOR, LORA_CODINGRATE,
                    LORA_PREAMBLE_LENGTH, LORA_FIX_LENGTH_PAYLOAD_ON,
                    true, 0, 0, LORA_IQ_INVERSION_ON, 3000);


  TimerInit(&autoGPS, onAutoGPS);

  gpsUpdate(GPS_INIT_TIMEOUT, GPS_CONTINUE_TIME);
  mcu_status = STATUS_LPM;

}






void loop() {
  

  switch (mcu_status) {
    case STATUS_LPM:
      lowPowerHandler();
      break;
    case STATUS_UPDATE_GPS:
      gpsUpdate(GPS_UPDATE_TIMEOUT, GPS_CONTINUE_TIME);
      mcu_status = STATUS_LPM;
      break;
    default:
      mcu_status = STATUS_LPM;
      break;
  }
}

/**
  * @brief  Double To String
  * @param  str: Array or pointer for storing strings
  * @param  double_num: Number to be converted
  * @param  len: Fractional length to keep
  * @retval None
  */
